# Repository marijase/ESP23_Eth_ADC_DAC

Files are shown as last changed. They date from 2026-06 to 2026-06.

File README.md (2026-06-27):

# Web-Controlled Stereo Signal Generator with Real-Time Signal Analysis

**Author:** Marija Sekulić
**Date:** June 2026

---

## About the project

The system generates digital audio signals of different waveforms (sine, square, triangle) on an ESP32-ETH01 microcontroller, converts them to analog signals using a PCM5102A digital-to-analog converter (DAC), then loops them back into the system through a WM8782S analog-to-digital converter (ADC) where they are analyzed in real time.

The user controls signal parameters — waveform, frequency, and amplitude — through a web application accessible over Ethernet or WiFi. The system displays detected frequency, RMS amplitude, and a real-time oscillogram of the received signal.

---

## Hardware

| Component | Role |
|---|---|
| **ESP32-ETH01** | Microcontroller with Ethernet and WiFi |
| **WM8782S** | 24-bit stereo audio ADC |
| **PCM5102A** | 32-bit stereo audio DAC |
| **USB-TTL adapter** | For firmware upload and serial monitoring |

---

## Features

- Real-time stereo audio signal generation (sine, square, triangle)
- 48 kHz sample rate, 16-bit resolution
- Independent control of left and right channels (frequency, amplitude, mute)
- RMS amplitude calculation
- Real-time signal oscillogram (10 updates per second)
- Responsive web application
- Dual network mode: Ethernet (primary) + WiFi AP (fallback)

---

## Repository structure

```
Projekat/
│
├── HW/                                Hardware
│   └── ESP32_Eth_ADC_DAC/             KiCad project (schematic + PCB)
│       ├── Libs/                      Custom KiCad libraries
│       │   └── ESP32_Eth_ADC_DAC.pretty/  Component footprints
│       ├── ESP32_Eth_ADC_DAC.kicad_pro
│       ├── ESP32_Eth_ADC_DAC.kicad_sch    Electrical schematic
│       ├── ESP32_Eth_ADC_DAC.kicad_pcb    PCB layout
│       └── ...
│
├── SW/                                Software
│   ├── signal_generator/              Main firmware
│   │   ├── signal_generator.ino       Arduino code
│   │   ├── webpage.h                  Web application (HTML/CSS/JS)
│   │   └── README.md
│   │
│   └── blinkanje/                     Test code (blink LED)
│       └── blinkanje.ino
│
└── docs/                              Documentation
    ├── datasheets/                    Component datasheets
    │   ├── ESP32_datasheet_en.pdf
    │   ├── WM8782_datasheet.pdf
    │   ├── WT32-ETH01_datasheet_V1.4_en.pdf
    │   ├── WT32-ETH01_EVO_Datasheet_V2.0_EN.pdf
    │   └── wt32-eth01-v1-4-serial-to-ethernet-module.pdf
    │
    └── dokumentacija.pdf    Main project documentation
```

---

## Technologies used

### Hardware protocols
- **I²S (Inter-IC Sound)** — digital audio protocol between microcontroller and audio chips
- **UART** — serial communication for firmware upload and debugging
- **RMII** — interface between ESP32 and LAN8720A Ethernet PHY chip

### Network protocols
- **Ethernet 10/100 Mbps** — via LAN8720A PHY
- **WiFi 802.11 b/g/n** — in Access Point mode (fallback)
- **HTTP** — web server for serving the page
- **WebSocket** — real-time bidirectional communication

### Software tools
- **Arduino IDE** with ESP32 board package v3.3.8 (Espressif)
- **KiCad** EDA suite for schematic and PCB
- **C/C++** — firmware
- **HTML / CSS / vanilla JavaScript** — web application
- **Chart.js** — library for signal visualization

---

## Pin mapping

### I²S TX (ESP32 master → DAC slave)
| ESP32 pin | DAC pin | Signal |
|---|---|---|
| IO15 (pin 20) | Pin 2 (BCK) | Bit clock |
| IO14 (pin 19) | Pin 4 (LCK) | LR clock |
| IO4 (pin 16) | Pin 3 (DIN) | Audio data |

### I²S RX (ADC master → ESP32 slave)
| ADC pin | ESP32 pin | Signal |
|---|---|---|
| Pin 1 (B) | IO36 (pin 21) | Bit clock |
| Pin 2 (LR) | IO39 (pin 22) | LR clock |
| Pin 3 (D) | IO35 (pin 17) | Audio data |

### Audio loopback
| From | To |
|---|---|
| DAC pin 7 (LROUT) | ADC pin 9 (Lin) |
| DAC pin 9 (ROUT) | ADC pin 7 (Rin) |

---

## Getting started

### 1. Hardware assembly

Connect the components according to the electrical schematic in `HW/ESP32_Eth_ADC_DAC/`. Detailed instructions and connection tables are available in the main documentation.

### 2. ADC module configuration

Set the DIP switch on the WM8782S module:

| Switch | Position | Function |
|---|---|---|
| 1 (M/S) | + | Master mode |
| 2 (Format) | 0 | I²S format |
| 3 (Sample rate) | − | 48 kHz |
| 4 (Bits) | − | 16-bit |

### 3. Development environment setup

1. Install **Arduino IDE** (from arduino.cc)
2. Add ESP32 board package:
   - File → Preferences → Additional Boards Manager URLs:
     `https://espressif.github.io/arduino-esp32/package_esp32_index.json`
   - Tools → Board → Boards Manager → install **esp32** (v3.3.8)
3. Install **WebSockets** library (Markus Sattler) via Library Manager

### 4. Arduino IDE configuration

- Tools → Board → esp32 → **WT32-ETH01 Ethernet Module**
- Upload Speed: **115200**
- Flash Frequency: **80MHz**
- Flash Mode: **QIO**
- Partition Scheme: **Default 4MB with spiffs**

### 5. Firmware upload

1. Unplug USB-TTL from the laptop
2. Connect ESP32 IO0 (pin 24) to GND (boot mode)
3. Plug in USB-TTL
4. Open `SW/signal_generator/signal_generator.ino`
5. Click **Upload**
6. During "Connecting...." unplug and plug EN pin back
7. After upload: unplug USB, remove IO0 from GND, plug USB back

### 6. Accessing the web application

**Via Ethernet cable (recommended):**
1. Connect a UTP cable from the ESP32 RJ45 to a free LAN port on the router
2. Open Serial Monitor (115200 baud) and read the IP address
3. Open that IP address in a browser

**Via WiFi AP (fallback):**
1. Connect to the WiFi network **ESP32-Signal-Generator** (password: `12345678`)
2. Open `http://192.168.4.1` in a browser

---

## Technical details

### I²S configuration

The ESP32 has two independent I²S controllers:
- **I²S0** — master TX channel to the DAC (generates BCK and LRCK)
- **I²S1** — slave RX channel from the ADC (receives BCK and LRCK from the ADC)

Since the WM8782S ADC is configured as master (using its onboard 24.576 MHz and 22.5792 MHz crystals), and the PCM5102A DAC is always a slave, using both ESP32 I²S controllers is required.

### Signal generation

Audio samples are computed in software, sample by sample (48000 times per second per channel), in the main loop. For each sample the current signal phase is calculated and converted to a 16-bit signed integer, which is written to the I²S DMA buffer.

### Signal analysis

- **RMS amplitude:** square root of the mean of squared samples in the buffer
- **Frequency:** zero-crossing detection (number of negative-to-positive transitions divided by buffer duration)

### WebSocket communication

Bidirectional real-time communication on port 81:
- **ESP32 → client:** 10 updates per second with JSON payload (detected frequency, RMS, array of 128 samples for oscillogram)
- **Client → ESP32:** commands on every slider move or button click

---

## Demonstration

The system supports the following features for demonstration:

- **Stereo signal generation** — different frequencies on L and R channels simultaneously
- **Real-time waveform switching** — sine, square, triangle
- **Independent channel muting**
- **Audio output via 3.5mm jack** — direct headphone connection
- **Real-time visualization** — oscillogram of the received signal
- **Dual-mode networking** — automatic fallback from Ethernet to WiFi AP

---

## License
...

---

# Youtube video:
[text](https://youtu.be/xQKN2IF4LF8?si=VLTadd05omXWZXxb)

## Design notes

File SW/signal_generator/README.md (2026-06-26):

# Signal Generator + Monitor

ESP32-ETH01 + WM8782S ADC + PCM5102A DAC sa web kontrolama preko Ethernet/WiFi.

---

## Šta projekat radi

1. ESP32 generiše stereo audio signal (sinus / kvadrat / trougao) i šalje ga DAC-u preko I²S
2. DAC ga pretvara u analogni signal koji ide u zvučnik / loopback ka ADC-u
3. ADC snima taj signal i šalje ga nazad ESP32-u
4. ESP32 analizira primljeni signal (frekvencija, RMS amplituda)
5. Web stranica prikazuje rezultate u realnom vremenu i omogućava kontrolu

---

## Sadržaj foldera

```
signal_generator/
├── signal_generator.ino     ← glavni Arduino fajl
├── webpage.h                ← HTML/CSS/JS web stranica
└── README.md                ← ovaj fajl
```

**Važno:** folder MORA da se zove `signal_generator` jer je glavni fajl `signal_generator.ino`. Arduino IDE zahteva da se folder zove isto kao i glavni .ino fajl.

---

## Priprema Arduino IDE-a

### 1. Instalacija ESP32 board package-a

Verovatno već imaš (verzija 3.3.8). Ako ne:
- File → Preferences → Additional Boards Manager URLs:
  `https://espressif.github.io/arduino-esp32/package_esp32_index.json`
- Tools → Board → Boards Manager → traži "esp32" → instaliraj

### 2. Instalacija dodatnih biblioteka

Sketch → Include Library → Manage Libraries → traži i instaliraj:

| Biblioteka | Autor |
|---|---|
| **WebSockets** | Markus Sattler |

Ostale (`WebServer`, `WiFi`, `ETH`, `driver/i2s.h`) dolaze sa ESP32 board package-om.

### 3. Selekcija board-a

- Tools → Board → esp32 → **"WT32-ETH01"**

Ako "WT32-ETH01" nije izlistan, izaberi **"ESP32 Dev Module"** — sve radi isto.

### 4. Upload settings

- Upload Speed: **115200**
- CPU Frequency: **240MHz**
- Flash Frequency: **40MHz**
- Flash Size: **4MB (32Mb)**
- Partition Scheme: **Default 4MB**

---

## Upload koda na ESP32

ESP32-ETH01 nema USB port — koristi USB-UART dongle, baš kao za blink test.

### Povezivanje za upload

```
USB-UART dongle    ESP32-ETH01
─────────────────  ─────────────
    TX        →    pin 7  (RXD)
    RX        →    pin 8  (TXD)
    GND       →    pin 2  (GND)
    5V        →    pin 12 (5V)
```

### Procedura uploada

1. **Pripremi za boot mod:** spoji IO0 (pin 24) na GND
2. **Resetuj ESP32:** kratko prekini napajanje (skini i vrati USB dongle)
3. U Arduino IDE klikni **Upload**
4. Sačekaj da se završi (~30 sekundi)
5. **Otkači IO0 sa GND-a**
6. Ponovo resetuj ESP32 (prekini napajanje)

Ako ne ide, proveri da li su TX/RX žice zamenjene — to je najčešća greška.

---

## Pristup web stranici

### Preko Ethernet kabla (default)

1. Spoji RJ45 kabl od ESP32-ETH01 na router (ili direktno na laptop)
2. Otvori **Serial Monitor** u Arduino IDE (115200 baud)
3. Resetuj ESP32 — videćeš ispis sa IP adresom, npr:
   ```
   [ETH] IP adresa: 192.168.1.123
   Otvori u pretrazivacu: http://192.168.1.123
   ```
4. Otvori tu IP adresu u pretraživaču na laptopu/telefonu

### Preko WiFi-ja (fallback)

Ako Ethernet kabl nije povezan u roku od 3 sekunde od starta, ESP32 automatski pokreće WiFi Access Point:

1. Na telefonu/laptopu uđi u WiFi podešavanja
2. Poveži se na mrežu **"ESP32-Signal-Generator"** sa lozinkom **"12345678"**
3. Otvori u pretraživaču: **http://192.168.4.1**

---

## Korišćenje web stranice

Stranica ima dva dela:

### Levi kanal (L) i Desni kanal (R)

Za svaki kanal možeš nezavisno podesiti:
- **Oblik talasa**: Sinus / Kvadrat / Trougao
- **Frekvencija**: klizač 100–5000 Hz
- **Amplituda**: klizač 0–100%
- **Mute**: dugme za isključivanje kanala

### Analiza primljenog signala (loopback)

Ispod kontrola, za svaki kanal prikazuje se:
- **Detektovana frekvencija** — koja bi trebalo da bude jednaka onoj koju šalješ (ovo dokazuje da loopback radi)
- **RMS amplituda** — efektivna jačina signala

### Oscilogram

Donji deo stranice prikazuje grafiku primljenog signala (oba kanala) u realnom vremenu, 10 puta u sekundi.

---

## Šta očekivati pri prvom pokretanju

Posle uspešnog uploada i resetovanja, na **Serial Monitor**-u trebalo bi da vidiš:

```
================================================
  Signal Generator + Monitor
  ESP32-ETH01 + WM8782S ADC + PCM5102A DAC
================================================

[INIT] Pokusavam Ethernet...
[ETH] Start
[ETH] Kabl povezan
[ETH] IP adresa: 192.168.1.123
[INIT] Ethernet aktivan
[I2S] Inicijalizacija TX (DAC) - master mod...
[I2S TX] OK
[I2S] Inicijalizacija RX (ADC) - slave mod...
[I2S RX] OK
[HTTP] Server pokrenut na portu 80
[WS] Server pokrenut na portu 81

================================================
  Otvori u pretrazivacu: http://192.168.1.123
================================================
```

---

## Troubleshooting

### Problem: Upload ne uspeva

- IO0 mora biti na GND tokom uploada
- TX/RX žice mogu biti zamenjene
- Resetuj ESP32 pre kliktanja Upload

### Problem: Stranica se učitava ali analiza pokazuje 0 Hz

- Loopback (DAC LROUT → ADC Lin) nije fizički povezan
- Proveri jumpere JP5 i JP6 — moraju biti zatvoreni
- DAC XSMT pin mora biti na 3.3V (un-mute)

### Problem: Detektovana frekvencija je dvostruko veća/manja

- Sample rate ADC i DAC nisu sinhronizovani
- Proveri DIP switch na ADC modulu — svi OFF (default)

### Problem: Šum / pucketanje u signalu

- Loš jumper kabl ili labava veza
- Proveri da li su sve GND linije spojene
- Možda treba decoupling kondenzator (100nF + 10μF) između VIN i GND na svakom modulu

### Problem: Nema pristupa web stranici

- Proveri IP adresu na Serial Monitor-u
- Proveri da li si u istoj mreži kao ESP32
- Probaj ping na IP adresu sa laptopa

---

## Tehnički detalji

| Parametar | Vrednost |
|---|---|
| Sample rate | 48 kHz |
| Bit dubina | 16-bit signed |
| Kanali | Stereo (L + R nezavisno) |
| I²S TX kontroler | I2S_NUM_0, ESP32 master |
| I²S RX kontroler | I2S_NUM_1, ESP32 slave (ADC je master) |
| Mreža | Ethernet + WiFi AP fallback |
| HTTP port | 80 |
| WebSocket port | 81 |
| Real-time prikaz | 10× u sekundi |

---

## Pinovi (rekapitulacija prema KiCad šemi)

| Funkcija | ESP32 GPIO | Komponenta |
|---|---|---|
| I²S TX BCLK | IO15 | DAC pin 2 (BCK) |
| I²S TX LRCK | IO14 | DAC pin 4 (LCK) |
| I²S TX DATA | IO4 | DAC pin 3 (DIN) |
| I²S RX BCLK | IO36 | ADC pin 1 (B) |
| I²S RX LRCK | IO39 | ADC pin 2 (LR) |
| I²S RX DATA | IO35 | ADC pin 3 (D) |

---

Marija Sekulić · RTRK · jun 2026

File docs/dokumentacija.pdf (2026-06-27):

# Dokumentacija projekta

### Web-kontrolisani stereo signal generator sa analizom signala u realnom vremenu

ESP32-ETH01 + WM8782S ADC + PCM5102A DAC

Student: Marija Sekulić RA194/2022
Predmet: Logičko projektovanje računarskih sistema 2

Fakultet tehničkih nauka, Univerzitet u Novom Sadu jun 2026.

## 1. Uvod

Cilj projekta je realizacija sistema koji generiše digitalne audio signale različitih oblika (sinus, kvadrat, trougao) preko ESP32-ETH01 mikrokontrolera, konvertuje ih u analogne signale pomoću PCM5102A DAC-a, i kroz loopback povratnu spregu vraća u sistem preko WM8782S ADC-a gde se analiziraju u realnom vremenu.

Korisnik upravlja parametrima signala kroz web aplikaciju dostupnu preko Ethernet ili WiFi mreže. Sistem prikazuje detektovanu frekvenciju, RMS amplitudu i oscilogram primljenog signala u realnom vremenu.

### Komponente sistema

- ESP32-ETH01
- WM8782S ADC
- PCM5102A DAC
- USB-TTL adapter

### Faze projekta

- Istraživanje komponenti i analiza pinova
- Projektovanje električne šeme i PCB-a u KiCad-u
- Fizička realizacija na breadboard-u i lemljenje PCB-a
- Razvoj firmvera (Arduino IDE, C/C++) i web aplikacije

## 2. Analiza komponenti

Prvi korak je bila analiza svake komponente — proučavanje datasheet-ova, određivanje uloga svakog pina i planiranje načina povezivanja.

### 2.1 ESP32-ETH01

Modul koji kombinuje ESP32 čip (procesor sa ugrađenim WiFi i Bluetooth) sa LAN8720A Ethernet PHY čipom i RJ45 konektorom. Programiranje preko spoljnog USB-TTL adaptera.

Karakteristike

Parametar | Vrednost
Radni napon | +5 V (preko regulatora) ili +3.3 V
Logički nivo GPIO | 3.3 V
Tipična potrošnja | ~80–160 mA
Ethernet brzina | 10/100 Mbps (LAN8720A PHY)
WiFi | 802.11 b/g/n
Procesor | Xtensa LX6 dvojezgarni, do 240 MHz
Memorija | 520 KB SRAM, 4 MB Flash

Korišćeni pinovi

Pin | Naziv | Tip | Uloga
1 | EN | Ulazni | Enable, na +3.3V
2 | GND | Napajanje | Masa
3 | 3V3 | Napajanje (izlaz) | Izlaz 3.3V regulatora
7 | RXD | Ulazni UART | UART prijem
8 | TXD | Izlazni UART | UART predaja
12 | 5V | Napajanje | Glavno +5V napajanje
16 | IO4 | I/O | I²S DATA OUT (ka DAC)
17 | IO35 | Samo ulazni | I²S DATA IN (od ADC)
19 | IO14 | I/O | I²S TX LRCK (ka DAC)
20 | IO15 | I/O | I²S TX BCLK (ka DAC)
21 | IO36 | Samo ulazni | I²S RX BCLK (od ADC)
22 | IO39 | Samo ulazni | I²S RX LRCK (od ADC)
24 | IO0 | I/O + boot | Boot mod (na GND pri uploadu)

### 2.2 PCM5102A — Stereo audio DAC

32-bitni stereo digitalno-analogni konvertor sa I²S ulazom (Texas Instruments). Modul ima ugrađen low-jitter PLL koji generiše interni system clock iz BCK signala (zbog čega se SCK pin vezuje na masu), i 3.5 mm audio jack za direktno priključivanje slušalica.

Karakteristike

Parametar | Vrednost
Radni napon | +3.3 V do +5 V
Rezolucija | 32 bita (radi i sa 16/24-bitnim)
Sample rate | 8 kHz – 384 kHz
SNR | 112 dB (A-weighted)
Maksimalni izlaz | 2.1 Vrms
Master/Slave | Uvek SLAVE

Pinovi

Pin | Naziv | Tip | Uloga
1 | SCK | Ulazni (takt) | System clock — na GND (interna PLL)
2 | BCK | Ulazni (takt) | Bit clock – od ESP32 IO15
3 | DIN | Ulazni | Audio podaci – od ESP32 IO4
4 | LCK | Ulazni (takt) | LR clock – od ESP32 IO14
5 | GND | Napajanje | Digitalna masa
6 | VIN | Napajanje | Napajanje +5V
7 | LROUT | Analogni izlaz | Levi audio izlaz
8 | AGND | Napajanje | Analogna masa
9 | ROUT | Analogni izlaz | Desni audio izlaz
10 | AGND | Napajanje | Analogna masa
11 | A3V3 | Napajanje | Analogno napajanje +3.3V
12 | FMT | Kontrolni | Audio format (GND = I²S)
13 | XSMT | Kontrolni | Soft mute (3.3V = un-mute)
14 | DEMP | Kontrolni | De-emphasis (GND = off)
15 | FLT | Kontrolni | Filter (GND = normal)

### 2.3 WM8782S — Stereo audio ADC

24-bitni stereo analogno-digitalni konvertor sa I²S izlazom. Modul ima dva kristalna oscilatora (24.576 MHz i 22.5792 MHz) za različite familije sample rate-a, AMS1117 LDO regulator napona 3.3V, DIP switch za izbor moda, i elektrolitske kondenzatore na analognim ulazima.

Karakteristike

Parametar | Vrednost
Radni napon | +5 V (preko AMS1117 regulatora)
Rezolucija | 24 bita
Sample rate | 32 / 44.1 / 48 / 88.2 / 96 / 192 kHz
SNR | 100 dB (A-weighted)
Maksimalni ulaz | 2 Vrms
Master/Slave | MASTER (u ovom modulu)

Pinovi

Pin | Naziv | Tip | Uloga
1 | B (BCK) | Izlazni | Bit clock — ka ESP32 IO36
2 | LR (LRCK) | Izlazni | LR clock — ka ESP32 IO39
3 | D (DATA) | Izlazni | Audio podaci — ka ESP32 IO35
4 | CLK
| (MCLK) | Izlazni | Master clock — nepovezan
5 | GND | Napajanje | Masa
6 | +5V | Napajanje | Napajanje +5V
7 | Rin | Analogni ulaz | Desni audio ulaz
9 | Lin | Analogni ulaz | Levi audio ulaz

DIP switch
Modul ima 4 prekidača za izbor moda. U projektu se koristi default konfiguracija — svi prekidači u poziciji 0 (OFF).

## 3. Povezivanje komponenti

U I²S komunikaciji jedan uređaj je master (generiše takte BCK i LRCK), a drugi je slave (samo prima takte). U ovom sistemu:

- WM8782S ADC je MASTER — koristi sopstvene kristale za BCK i LRCK
- PCM5102A DAC je SLAVE — prima takte i podatke spolja
- ESP32 je istovremeno MASTER i SLAVE — koristi dva I²S kontrolera. I²S0 master (TX → DAC), I²S1 slave (RX ← ADC)

Napajanje

Od | Pin | Do | Pin
USB-TTL | 5V | šina protoborda | +5V
USB-TTL | GND | šina protoborda | GND
+5V šina | — | ESP32-ETH01 | Pin 12 (5V)
+5V šina | — | WM8782S ADC | +5V
+5V šina | — | PCM5102A DAC | Pin 6 (VIN)
ESP32-ETH01 | Pin 3 (3V3) | +3.3V šina | —
+3.3V šina | — | ESP32-ETH01 | Pin 1 (EN)
+3.3V šina | — | PCM5102A DAC | Pin 11 (A3V3)
+3.3V šina | — | PCM5102A DAC | Pin 13 (XSMT)

I²S TX (ESP32 → DAC)

Od | Pin | Do | Pin
ESP32 | IO15 (pin 20) | DAC | Pin 2 (BCK)
ESP32 | IO14 (pin 19) | DAC | Pin 4 (LCK)
ESP32 | IO4 (pin 16) | DAC | Pin 3 (DIN)
GND | — | DAC | Pin 1 (SCK)

I²S RX (ADC → ESP32)

Od | Pin | Do | Pin
ADC | Pin 1 (B) | ESP32 | IO36 (pin 21)
ADC | Pin 2 (LR) | ESP32 | IO39 (pin 22)
ADC | Pin 3 (D) | ESP32 | IO35 (pin 17)

DAC kontrolni pinovi

DAC pin | Veza | Značenje
Pin 12 (FMT) | GND | I²S format
Pin 14 (DEMP) | GND | De-emphasis off
Pin 15 (FLT) | GND | Normal latency
Pin 13 (XSMT) | +3.3V | Un-mute (DAC aktivan)
Pin 8, 10 (AGND) | GND | Analogna masa

Audio loopback (DAC → ADC)
Glavna veza projekta — analogni izlaz DAC-a direktno se vraća u ADC ulaz, što omogućava verifikaciju da li je signal koji je sistem generisao uspešno reprodukovan i ponovo digitalizovan.
Od | Pin | Do | Pin
DAC | Pin 7 (LROUT) | ADC | Pin 9 (Lin)
DAC | Pin 9 (ROUT) | ADC | Pin 7 (Rin)

UART (programiranje)

Od | Pin | Do | Pin
USB-TTL | TX | ESP32 | Pin 7 (RXD)
USB-TTL | RX | ESP32 | Pin 8 (TXD)

## 4. Električna šema i PCB

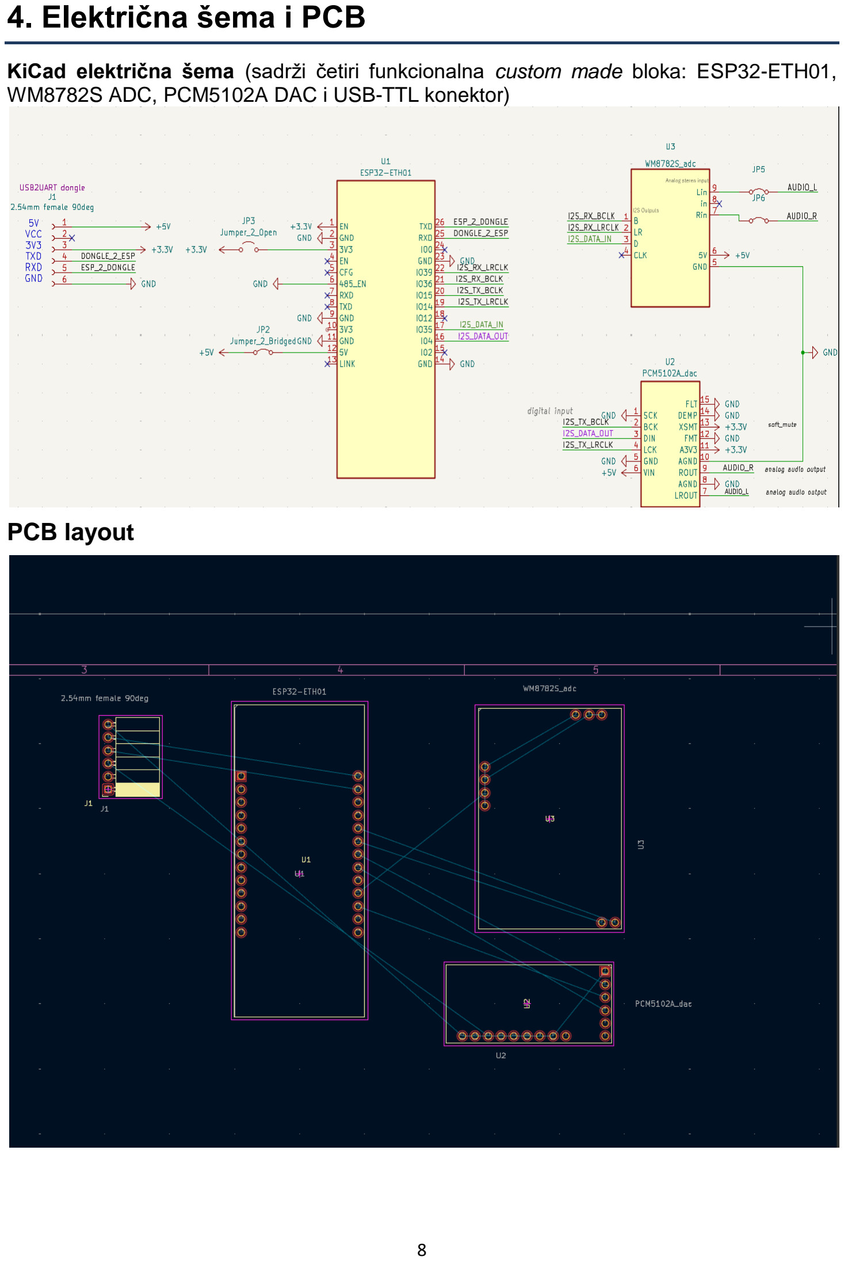
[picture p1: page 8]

KiCad električna šema (sadrži četiri funkcionalna custom made bloka: ESP32-ETH01, WM8782S ADC, PCM5102A DAC i USB-TTL konektor)

### PCB layout

## 5. Fizička realizacija

Pre lemljenja PCB-a, sistem je sastavljen na breadboard-u (protobordu) i testiran. Ovaj korak omogućava verifikaciju ispravnosti šeme i firmvera pre konačnog lemljenja. Komponente su
povezane | jumper | kablovima | prema | tabeli | veza | iz | poglavlja | 3.

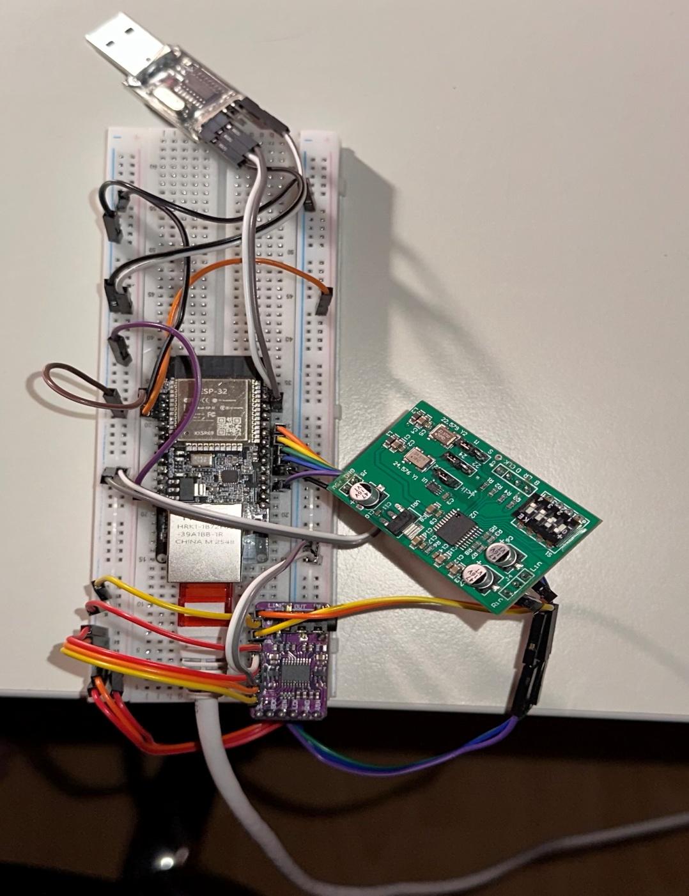
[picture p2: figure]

### 5.1 Provera ispravnosti pre uključenja

Pre prvog uključenja sistema izvršena je sistematska provera povezivanja digitalnim multimetrom (VC830L):

- Provera otpornosti između +5V i GND linija (ne sme pokazati 0Ω — kratak spoj)
- Provera otpornosti između +3.3V i GND linija
- Provera kontinuiteta svake mase prema zajedničkoj GND šini
- Provera da su +5V i +3.3V odvojene linije (ne smeju biti spojene)

### 5.2 Provera napona nakon uključenja

Tačka | Očekivano | Značenje
+5V šina | ~5 V | Napajanje stiže
ESP32 pin 3 (3V3) | ~3.3 V | ESP32 regulator radi
DAC pin 11 (A3V3) | ~3.3 V | DAC analogno napajanje
ADC +5V | ~5 V | ADC napajanje
DAC pin 1 (SCK) | 0 V | System clock na GND
DAC pin 13 (XSMT) | ~3.3 V | DAC nije muted

## 6. Softverska realizacija

Projekat je razvijen u Arduino IDE okruženju (C/C++ jezik, ESP32 board package 3.3.8). Web aplikacija u HTML/CSS/JavaScript-u, koristeći Chart.js biblioteku za vizualizaciju signala.

Struktura projekta:
- signal_generator.ino - Glavni firmware — I²S, generisanje signala, analiza, mreža
- webpage.h - HTML/CSS/JavaScript web aplikacije (u flash memoriji)

### 6.1 I²S protokol

I²S (Inter-IC Sound) je serijski protokol za prenos digitalnog audio signala između integrisanih kola. Razvijen od strane Philips-a 1986. godine, danas je industrijski standard za digitalni audio.

Signali u I²S protokolu
- BCLK (Bit Clock) — sat koji odbrojava svaki bit podataka. Za 48 kHz / 16-bit / stereo: 48000 × 16 × 2 = 1.536 MHz
- LRCK / WS (Word Select) — sat koji bira da li se prenosi levi ili desni kanal. Frekvencija = sample rate (48 kHz)
- SD / DATA — serijska linija sa audio podacima (16-bitni signed integer)

ESP32 I²S konfiguracija
ESP32 ima dva nezavisna I²S kontrolera. U projektu je I²S0 konfigurisan kao master TX (šalje podatke DAC-u), a I²S1 kao slave RX (prima podatke od ADC-a). Sample rate 48 kHz, bitska dubina 16, format stereo.

### 6.2 Mrežna komunikacija

Sistem podržava dva načina pristupa web aplikaciji — Ethernet (primarni) i WiFi Access Point (rezervni). Pri startu, firmware pokušava Ethernet konekciju; ako u 3 sekunde nije detektovan kabl, prebacuje se na WiFi.
Ethernet - ESP32 – ETH01 koristi LAN8720A PHY čip sa RMII interfejsom. Konekcija sa lokalnom mrežom preko UTP kabla i kućnog rutera, koji dodeljuje IP adresu kroz DHCP.

WiFi Access Point – Ako Ethernet nije dostupan, ESP32 pokreće WiFi mrežu sa SSID "ESP32-Signal-Generator" i lozinkom "12345678". Aplikacija je dostupna na http://192.168.4.1.

### 6.3 HTTP server

Firmware sadrži HTTP server (biblioteka WebServer.h) koji slušа na portu 80. Dve glavne rute:

- GET / — vraća HTML stranicu (iz webpage.h)
- GET /status — vraća JSON sa trenutnim stanjem sistema

### 6.4 WebSocket protokol

WebSocket je protokol koji omogućava dvosmernu komunikaciju u realnom vremenu između web pretraživača i ESP32-a. Za razliku od HTTP-a (request-response model), WebSocket uspostavlja trajnu vezu preko koje obe strane mogu slati poruke u bilo kom trenutku.

U projektu se koristi za dva smera:
- ESP32 → pretraživač: 10 puta u sekundi šalje JSON sa detektovanom frekvencijom, RMS amplitudom i 128 uzoraka signala za oscilogram
- Pretraživač → ESP32: pri pomeranju klizača šalje komandu ("freq_left=2000", "wave_right=1") koja se odmah primenjuje
WebSocket server radi na portu 81 (Markus Sattler WebSockets biblioteka, v2.7.2).

### 6.5 Generisanje signala

Sinusni, kvadratni i trougaoni signali se računaju u softveru, uzorak po uzorak (48000 puta u sekundi po kanalu) u glavnoj petlji. Za svaki uzorak se izračuna trenutna faza, konvertuje u 16-bitni signed integer i upiše u I²S DMA buffer.

Sinusni: y = sin(2π × f × t). Kvadratni: y = ±1 zavisno od znaka sin(2π × f × t). Trougaoni: linearno rastuća pa opadajuća rampa.

Signal koji ESP32 prima od ADC-a se analizira u realnom vremenu:

- RMS amplituda — kvadratni koren prosečnog kvadrata uzoraka u baferu
- Detektovana frekvencija — metodom detekcije prelazaka kroz nulu (zero-crossing) — broji se prelaska iz negativne u pozitivnu vrednost i deli sa trajanjem bafera

### 6.6 Web aplikacija

Single-page aplikacija (sav HTML/CSS/JS u webpage.h fajlu). Tamni dizajn sa dva panela (levi kanal — plavi, desni — narandžasti), klizače za frekvenciju i amplitudu, dugmad za izbor oblika talasa, prikaz detektovanih vrednosti i oscilogram u realnom vremenu (Chart.js).

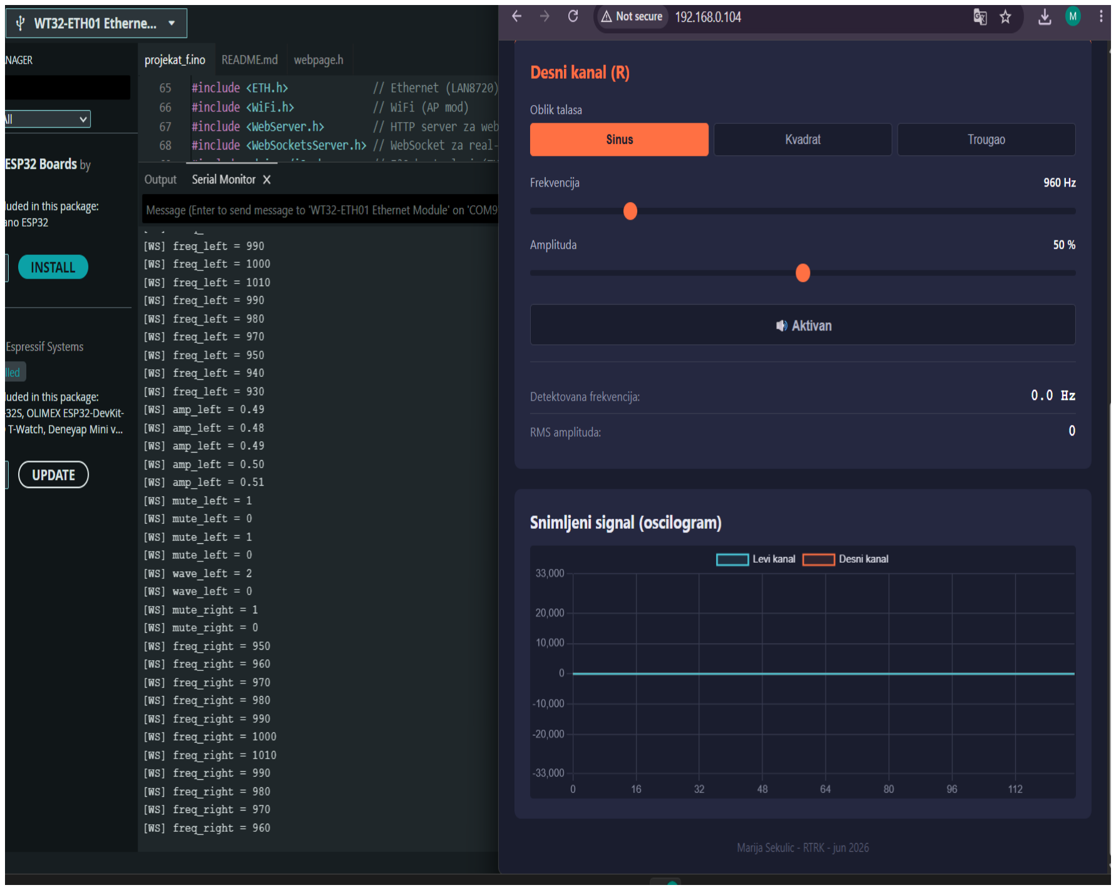
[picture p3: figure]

Pri otvaranju, JavaScript uspostavlja WebSocket konekciju i počinje da prima podatke od ESP32-a. Svako pomeranje klizača automatski šalje komandu, što omogućava trenutnu reakciju bez učitavanja stranice.

## 7. Zaključak

Sistem demonstrira kombinaciju više različitih tehnologija — embedded development, digitalna audio obrada (I²S protokol, ADC/DAC konvertori), poznavanje osnova elektronike (realizacija na breadboard-u), mrežne komunikacije (Ethernet, WiFi, HTTP) i web razvoj (responzivni dizajn, real-time vizualizacija).

Iz projekta je izostavljen deo lemljenja, pa je realizovan samo na protobordu, zbog čega su prisutne poteškoće prilikom prikaza ADC rezultata u aplikaciji, međutim ipak u jednom navratu je uspešno zabeležen i taj trenutak:

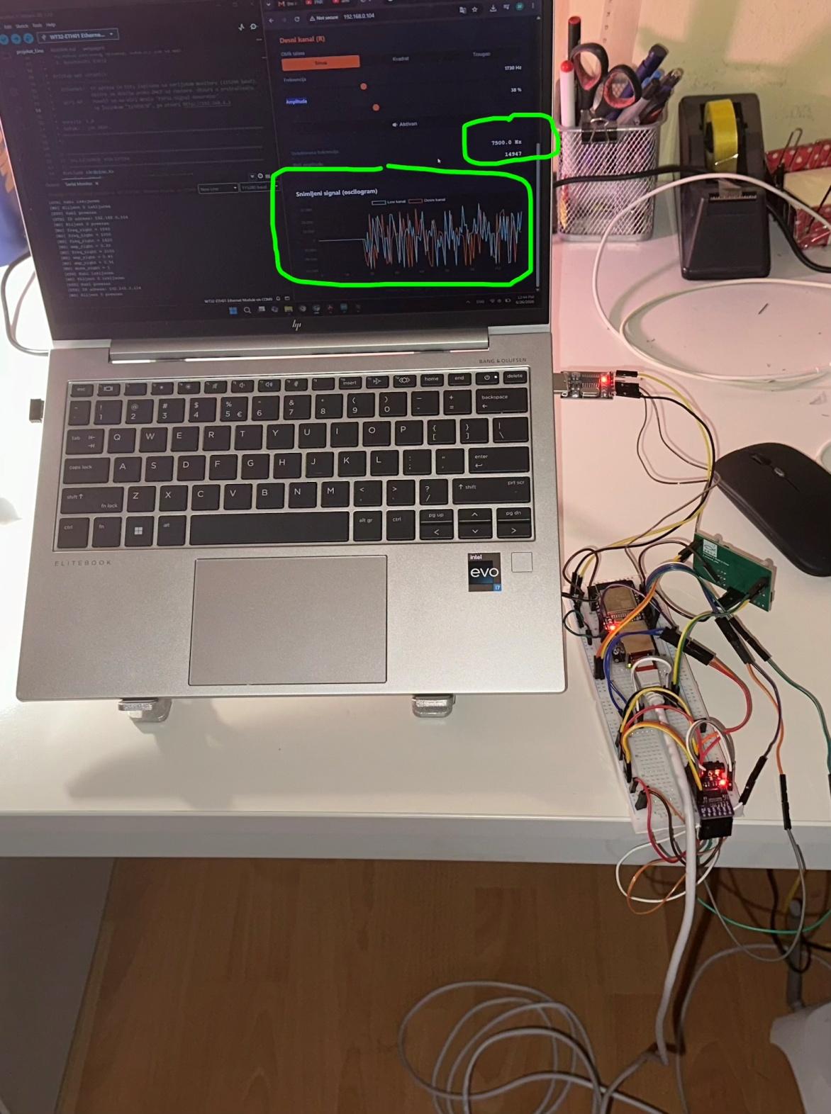
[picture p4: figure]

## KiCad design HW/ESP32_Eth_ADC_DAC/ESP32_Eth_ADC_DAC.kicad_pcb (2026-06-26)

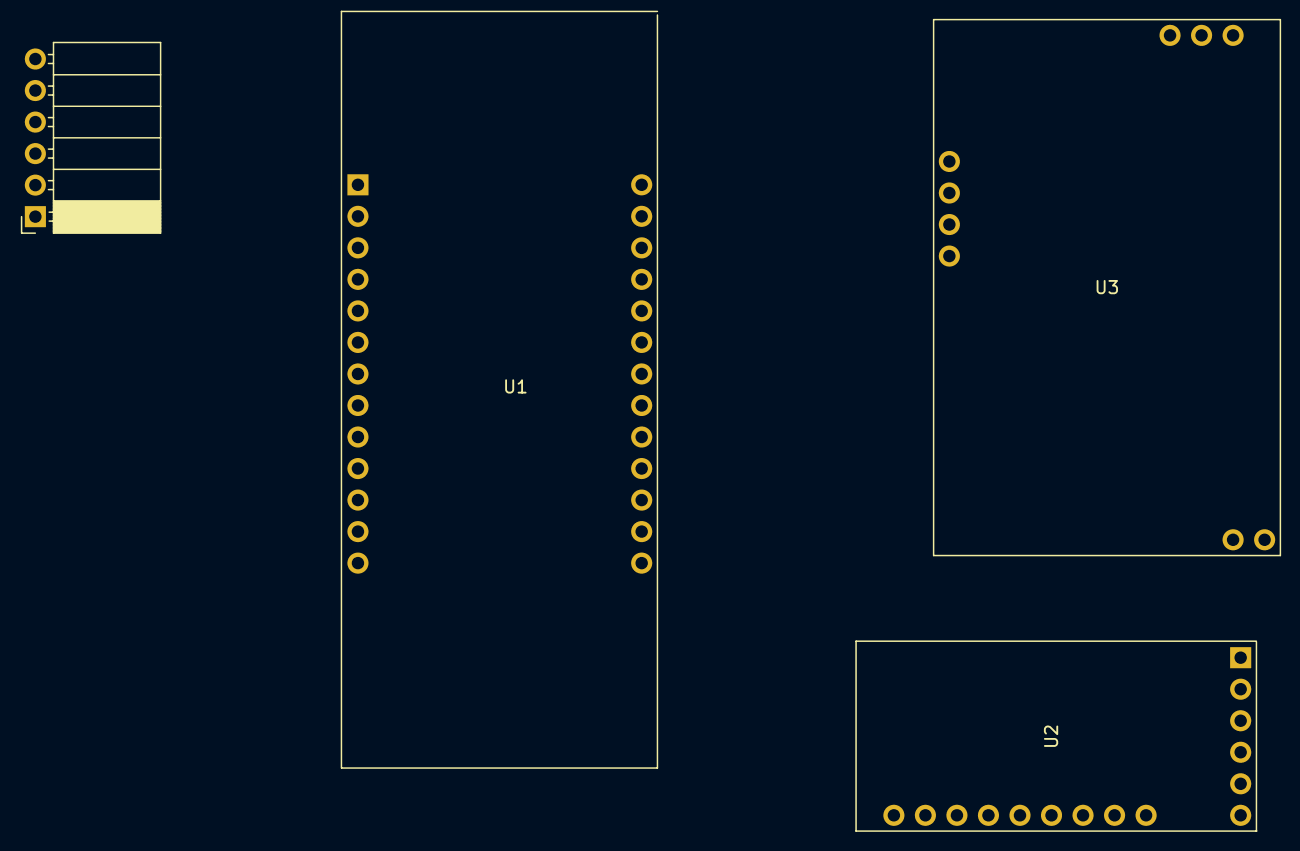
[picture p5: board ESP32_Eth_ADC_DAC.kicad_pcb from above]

Board: 2 copper layers, 4 parts (0 on the bottom side), 10 nets, no tracks yet.

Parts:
J1: 2.54mm female 90deg; PinSocket_1x06_P2.54mm_Horizontal
U1: ESP32-ETH01
U2: PCM5102A_dac
U3: WM8782S_adc

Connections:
+3.3V: J1.3, U2.11 (A3V3), U2.13 (XSMT)
/DONGLE_2_ESP: J1.4, U1.25 (RXD)
/ESP_2_DONGLE: J1.5, U1.26 (TXD)
/I2S_DATA_IN: U1.17 (IO35), U3.3 (D)
/I2S_DATA_OUT: U1.16 (IO4), U2.3 (DIN)
/I2S_RX_BCLK: U1.21 (IO36), U3.1 (B)
/I2S_RX_LRCLK: U1.22 (IO39), U3.2 (LR)
/I2S_TX_BCLK: U1.20 (IO15), U2.2 (BCK)
/I2S_TX_LRCLK: U1.19 (IO14), U2.4 (LCK)
GND: J1.6, U1.6 (485_EN), U2.1 (SCK), U2.8 (AGND), U2.10 (AGND), U2.12 (FMT), U2.14 (DEMP), U2.15 (FLT)

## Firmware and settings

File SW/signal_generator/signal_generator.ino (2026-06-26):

#include <Arduino.h>
#include <ETH.h>              // Ethernet (LAN8720)
#include <WiFi.h>             // WiFi (AP mod)
#include <WebServer.h>        // HTTP server for web page
#include <WebSocketsServer.h> // WebSocket for real-time data on graphic
#include <driver/i2s.h>       // I²S controllers (TX for DAC, RX for ADC)
#include <math.h>             // sin(), fabs()

#include "webpage.h"          // HTML/CSS/JS web page (array charactrers)


// ----- I²S TX (ESP32 → DAC) -----
#define I2S_TX_PORT       I2S_NUM_0
#define I2S_TX_BCLK_PIN   15      // → DAC pin 2 (BCK)
#define I2S_TX_LRCK_PIN   14      // → DAC pin 4 (LCK)
#define I2S_TX_DOUT_PIN    4      // → DAC pin 3 (DIN)

// ----- I²S RX (ADC → ESP32) -----
#define I2S_RX_PORT       I2S_NUM_1
#define I2S_RX_BCLK_PIN   36      // ← ADC pin 1 (B)
#define I2S_RX_LRCK_PIN   39      // ← ADC pin 2 (LR)
#define I2S_RX_DIN_PIN    35      // ← ADC pin 3 (D)

// ----- Audio parameters -----
#define SAMPLE_RATE       48000   // 48 kHz 
#define BITS_PER_SAMPLE   16      // 16-bit signed integer per sample per channel
#define BUFFER_SAMPLES    256     // size audio buffer (per channel)
#define DMA_BUF_COUNT     8       // DMA buffer number
#define DMA_BUF_LEN       64      // size of each DMA buff

// ----- Network -----
#define WIFI_AP_SSID      "ESP32-Signal-Generator"
#define WIFI_AP_PASSWORD  "12345678"
#define ETH_TIMEOUT_MS    3000    // 3 seconds for detection Ethernet connection
#define HTTP_PORT         80
#define WEBSOCKET_PORT    81

enum WaveformType {
  WAVEFORM_SINE     = 0,
  WAVEFORM_SQUARE   = 1,
  WAVEFORM_TRIANGLE = 2
};


bool eth_connected = false;
bool wifi_ap_active = false;
String active_network = "Initializing...";
String ip_address = "0.0.0.0";

WebServer http_server(HTTP_PORT);
WebSocketsServer ws_server(WEBSOCKET_PORT);

volatile WaveformType wave_left  = WAVEFORM_SINE;
volatile WaveformType wave_right = WAVEFORM_SINE;
volatile float freq_left  = 1000.0;  // Hz
volatile float freq_right = 1000.0;  // Hz
volatile float amp_left   = 0.5;     // 0.0 - 1.0
volatile float amp_right  = 0.5;     // 0.0 - 1.0
volatile bool  mute_left  = false;
volatile bool  mute_right = false;

double phase_left  = 0.0;
double phase_right = 0.0;

volatile float detected_freq_left  = 0.0;
volatile float detected_freq_right = 0.0;
volatile float rms_left            = 0.0;
volatile float rms_right           = 0.0;

// audio buffers  (interleaved L/R)
int16_t tx_buffer[BUFFER_SAMPLES * 2];  // 2 jer je stereo
int16_t rx_buffer[BUFFER_SAMPLES * 2];

#define GRAPH_SAMPLES 128
int16_t graph_buffer_left[GRAPH_SAMPLES];
int16_t graph_buffer_right[GRAPH_SAMPLES];

// time tracking 
unsigned long last_websocket_send = 0;
const unsigned long WEBSOCKET_INTERVAL_MS = 100;  // 10× per second

//  ETHERNET — handler event 
void onEthEvent(WiFiEvent_t event) {
  switch (event) {
    case ARDUINO_EVENT_ETH_START:
      Serial.println("[ETH] Start");
      ETH.setHostname("esp32-signal-gen");
      break;
    case ARDUINO_EVENT_ETH_CONNECTED:
      Serial.println("[ETH] Kabl povezan");
      break;
    case ARDUINO_EVENT_ETH_GOT_IP:
      Serial.print("[ETH] IP adresa: ");
      Serial.println(ETH.localIP());
      eth_connected = true;
      ip_address = ETH.localIP().toString();
      active_network = "Ethernet";
      break;
    case ARDUINO_EVENT_ETH_DISCONNECTED:
      Serial.println("[ETH] Kabl iskljucen");
      eth_connected = false;
      break;
    case ARDUINO_EVENT_ETH_STOP:
      Serial.println("[ETH] Stop");
      eth_connected = false;
      break;
    default:
      break;
  }
}

//  WiFi AP — as fallback
void startWiFiAP() {
  Serial.println("[WiFi] Pokretanje Access Point-a...");
  WiFi.mode(WIFI_AP);
  WiFi.softAP(WIFI_AP_SSID, WIFI_AP_PASSWORD);
  delay(500);
  IPAddress apIP = WiFi.softAPIP();
  Serial.print("[WiFi] AP aktivan. SSID: ");
  Serial.println(WIFI_AP_SSID);
  Serial.print("[WiFi] Lozinka: ");
  Serial.println(WIFI_AP_PASSWORD);
  Serial.print("[WiFi] IP adresa: ");
  Serial.println(apIP);
  wifi_ap_active = true;
  ip_address = apIP.toString();
  active_network = "WiFi AP";
}

//  I²S init— TX channel (for DAC, master mode)
void setupI2S_TX() {
  Serial.println("[I2S] Inicijalizacija TX (DAC) - master mod...");

  i2s_config_t tx_config = {
    .mode = (i2s_mode_t)(I2S_MODE_MASTER | I2S_MODE_TX),
    .sample_rate = SAMPLE_RATE,
    .bits_per_sample = (i2s_bits_per_sample_t)BITS_PER_SAMPLE,
    .channel_format = I2S_CHANNEL_FMT_RIGHT_LEFT,
    .communication_format = I2S_COMM_FORMAT_STAND_I2S,
    .intr_alloc_flags = ESP_INTR_FLAG_LEVEL1,
    .dma_buf_count = DMA_BUF_COUNT,
    .dma_buf_len = DMA_BUF_LEN,
    .use_apll = true,           // Audio PLL for excact sample rate
    .tx_desc_auto_clear = true,
    .fixed_mclk = 0
  };

  i2s_pin_config_t tx_pins = {
    .mck_io_num = I2S_PIN_NO_CHANGE,
    .bck_io_num = I2S_TX_BCLK_PIN,
    .ws_io_num  = I2S_TX_LRCK_PIN,
    .data_out_num = I2S_TX_DOUT_PIN,
    .data_in_num  = I2S_PIN_NO_CHANGE
  };

  esp_err_t err = i2s_driver_install(I2S_TX_PORT, &tx_config, 0, NULL);
  if (err != ESP_OK) {
    Serial.printf("[I2S TX] Greska install: %d\n", err);
    return;
  }
  err = i2s_set_pin(I2S_TX_PORT, &tx_pins);
  if (err != ESP_OK) {
    Serial.printf("[I2S TX] Greska set_pin: %d\n", err);
    return;
  }
  i2s_zero_dma_buffer(I2S_TX_PORT);
  Serial.println("[I2S TX] OK");
}

//  I²S init — RX channel (from ADC-a, slave mode)
//  ADC master, ESP32  slave <-   recieving BCK/LRCK from ADC
void setupI2S_RX() {
  Serial.println("[I2S] Inicijalizacija RX (ADC) - slave mod...");

  i2s_config_t rx_config = {
    .mode = (i2s_mode_t)(I2S_MODE_SLAVE | I2S_MODE_RX),
    .sample_rate = SAMPLE_RATE,
    .bits_per_sample = (i2s_bits_per_sample_t)BITS_PER_SAMPLE,
    .channel_format = I2S_CHANNEL_FMT_RIGHT_LEFT,
    .communication_format = I2S_COMM_FORMAT_STAND_I2S,
    .intr_alloc_flags = ESP_INTR_FLAG_LEVEL1,
    .dma_buf_count = DMA_BUF_COUNT,
    .dma_buf_len = DMA_BUF_LEN,
    .use_apll = false,          // slave modue = clk from ADC
    .tx_desc_auto_clear = false,
    .fixed_mclk = 0
  };

  i2s_pin_config_t rx_pins = {
    .mck_io_num = I2S_PIN_NO_CHANGE,
    .bck_io_num = I2S_RX_BCLK_PIN,
    .ws_io_num  = I2S_RX_LRCK_PIN,
    .data_out_num = I2S_PIN_NO_CHANGE,
    .data_in_num  = I2S_RX_DIN_PIN
  };

  esp_err_t err = i2s_driver_install(I2S_RX_PORT, &rx_config, 0, NULL);
  if (err != ESP_OK) {
    Serial.printf("[I2S RX] Greska install: %d\n", err);
    return;
  }
  err = i2s_set_pin(I2S_RX_PORT, &rx_pins);
  if (err != ESP_OK) {
    Serial.printf("[I2S RX] Greska set_pin: %d\n", err);
    return;
  }
  Serial.println("[I2S RX] OK");
}

//  generating single data (sample) — returns 16-bit signed int
inline int16_t generateSample(WaveformType wave, double &phase,
                              float freq, float amp, bool muted) {
  if (muted) return 0;

  // Inkrement phase — phase in rad [0, 2π)
  double phase_inc = (2.0 * M_PI * freq) / (double)SAMPLE_RATE;
  phase += phase_inc;
  if (phase >= 2.0 * M_PI) phase -= 2.0 * M_PI;

  double normalized = phase / (2.0 * M_PI);  // [0, 1)
  double value = 0.0;  // [-1, 1]

  switch (wave) {
    case WAVEFORM_SINE:
      value = sin(phase);
      break;
    case WAVEFORM_SQUARE:
      value = (normalized < 0.5) ? 1.0 : -1.0;
      break;
    case WAVEFORM_TRIANGLE:
      if (normalized < 0.5) {
        value = -1.0 + 4.0 * normalized;       //  -1 -->   1
      } else {
        value = 3.0 - 4.0 * normalized;        //  1  -->  -1
      }
      break;
  }

  // Skale with amplitude and convert in 16-bit signed
  //  0.9 max  (clipping DAC)
  double scaled = value * amp * 0.9 * 32767.0;
  if (scaled >  32767.0) scaled =  32767.0;
  if (scaled < -32768.0) scaled = -32768.0;
  return (int16_t)scaled;
}

//  analyze recieved signal — freq (zero-crossing) i RMS amplitude
void analyzeSignal(int16_t *samples, int count, int channel,
                   float &out_freq, float &out_rms) {
  // RMS = sqrt(mean(samples^2))
  double sum_sq = 0.0;
  for (int i = 0; i < count; i++) {
    double v = (double)samples[i];
    sum_sq += v * v;
  }
  out_rms = sqrt(sum_sq / (double)count);

  // Frekvencija pomoću zero-crossing detekcije
  // Brojimo koliko puta signal prelazi kroz nulu (sa - na +)
  int crossings = 0;
  for (int i = 1; i < count; i++) {
    if (samples[i-1] < 0 && samples[i] >= 0) {
      crossings++;
    }
  }
  // Vreme trajanja bafera (u sekundama)
  double duration = (double)count / (double)SAMPLE_RATE;
  if (duration > 0.0) {
    out_freq = (float)((double)crossings / duration);
  } else {
    out_freq = 0.0;
  }
}

// ============================================================================
//  POPUNJAVANJE TX bafera sa novim uzorcima
// ============================================================================
void fillTxBuffer() {
  for (int i = 0; i < BUFFER_SAMPLES; i++) {
    int16_t sL = generateSample(wave_left,  phase_left,  freq_left,  amp_left,  mute_left);
    int16_t sR = generateSample(wave_right, phase_right, freq_right, amp_right, mute_right);
    // Interleaved format: L, R, L, R, ...
    tx_buffer[i*2 + 0] = sL;
    tx_buffer[i*2 + 1] = sR;
  }
}

// ============================================================================
//  WEB SERVER handlers
// ============================================================================
void handleRoot() {
  // Serviraj glavnu HTML stranicu iz webpage.h
  http_server.send_P(200, "text/html", WEBPAGE_HTML);
}

void handleStatus() {
  // Vrati JSON sa trenutnim stanjem
  String json = "{";
  json += "\"network\":\""  + active_network + "\",";
  json += "\"ip\":\""        + ip_address    + "\",";
  json += "\"freq_left\":"   + String(freq_left, 1) + ",";
  json += "\"freq_right\":"  + String(freq_right, 1) + ",";
  json += "\"amp_left\":"    + String(amp_left, 2) + ",";
  json += "\"amp_right\":"   + String(amp_right, 2) + ",";
  json += "\"wave_left\":"   + String((int)wave_left) + ",";
  json += "\"wave_right\":"  + String((int)wave_right) + ",";
  json += "\"mute_left\":"   + String(mute_left  ? "true" : "false") + ",";
  json += "\"mute_right\":"  + String(mute_right ? "true" : "false") + ",";
  json += "\"sample_rate\":" + String(SAMPLE_RATE);
  json += "}";
  http_server.send(200, "application/json", json);
}

void handleNotFound() {
  http_server.send(404, "text/plain", "Not Found");
}

// ============================================================================
//  WebSocket handler — prima komande sa web stranice, šalje rezultate analize
// ============================================================================
void onWebSocketEvent(uint8_t client_num, WStype_t type,
                     uint8_t *payload, size_t length) {
  switch (type) {
    case WStype_CONNECTED:
      Serial.printf("[WS] Klijent %u povezan\n", client_num);
      break;
    case WStype_DISCONNECTED:
      Serial.printf("[WS] Klijent %u iskljucen\n", client_num);
      break;
    case WStype_TEXT: {
      // Format komande: "KEY=VALUE"
      String msg = String((char*)payload).substring(0, length);
      int eq = msg.indexOf('=');
      if (eq < 0) break;
      String key = msg.substring(0, eq);
      String val = msg.substring(eq + 1);

      if      (key == "wave_left")   wave_left   = (WaveformType)val.toInt();
      else if (key == "wave_right")  wave_right  = (WaveformType)val.toInt();
      else if (key == "freq_left")   freq_left   = val.toFloat();
      else if (key == "freq_right")  freq_right  = val.toFloat();
      else if (key == "amp_left")    amp_left    = val.toFloat();
      else if (key == "amp_right")   amp_right   = val.toFloat();
      else if (key == "mute_left")   mute_left   = (val == "1" || val == "true");
      else if (key == "mute_right")  mute_right  = (val == "1" || val == "true");

      Serial.printf("[WS] %s = %s\n", key.c_str(), val.c_str());
      break;
    }
    default:
      break;
  }
}

// ============================================================================
//  Slanje podataka analize i grafika preko WebSocket-a
// ============================================================================
void sendDataToClients() {
  // Formatiraj JSON sa svim podacima
  String json = "{\"type\":\"data\",";
  json += "\"network\":\"" + active_network + "\",";
  json += "\"detected_freq_left\":"  + String(detected_freq_left, 1) + ",";
  json += "\"detected_freq_right\":" + String(detected_freq_right, 1) + ",";
  json += "\"rms_left\":"  + String(rms_left, 1) + ",";
  json += "\"rms_right\":" + String(rms_right, 1) + ",";

  // Niz uzoraka za grafik (downsample-ovan)
  json += "\"graph_left\":[";
  for (int i = 0; i < GRAPH_SAMPLES; i++) {
    json += String(graph_buffer_left[i]);
    if (i < GRAPH_SAMPLES - 1) json += ",";
  }
  json += "],\"graph_right\":[";
  for (int i = 0; i < GRAPH_SAMPLES; i++) {
    json += String(graph_buffer_right[i]);
    if (i < GRAPH_SAMPLES - 1) json += ",";
  }
  json += "]}";

  ws_server.broadcastTXT(json);
}

// ============================================================================
//  SETUP
// ============================================================================
void setup() {
  Serial.begin(115200);
  delay(500);
  Serial.println();
  Serial.println("================================================");
  Serial.println("  PROJEKAT F - Signal Generator + Monitor");
  Serial.println("  ESP32-ETH01 + WM8782S ADC + PCM5102A DAC");
  Serial.println("================================================");

  // ----- 1. Pokušaj Ethernet konekcije -----
  Serial.println("\n[INIT] Pokusavam Ethernet...");
  WiFi.onEvent(onEthEvent);
  ETH.begin();

  unsigned long start = millis();
  while (!eth_connected && (millis() - start < ETH_TIMEOUT_MS)) {
    delay(100);
  }

  // ----- 2. Ako Ethernet nije uspeo, pokreni WiFi AP -----
  if (!eth_connected) {
    Serial.println("[INIT] Ethernet nije aktivan posle 3s -> startujem WiFi AP");
    startWiFiAP();
  } else {
    Serial.println("[INIT] Ethernet aktivan");
  }

  // ----- 3. Inicijalizuj I²S kanale -----
  setupI2S_TX();
  setupI2S_RX();

  // ----- 4. Inicijalizuj HTTP server -----
  http_server.on("/", handleRoot);
  http_server.on("/status", handleStatus);
  http_server.onNotFound(handleNotFound);
  http_server.begin();
  Serial.printf("[HTTP] Server pokrenut na portu %d\n", HTTP_PORT);

  // ----- 5. Inicijalizuj WebSocket server -----
  ws_server.begin();
  ws_server.onEvent(onWebSocketEvent);
  Serial.printf("[WS] Server pokrenut na portu %d\n", WEBSOCKET_PORT);

  Serial.println("\n================================================");
  Serial.print("  Otvori u pretrazivacu: http://");
  Serial.println(ip_address);
  Serial.println("================================================\n");
}

// ============================================================================
//  LOOP — glavna petlja
// ============================================================================
void loop() {
  // ----- 1. Obradi HTTP i WebSocket -----
  http_server.handleClient();
  ws_server.loop();

  // ----- 2. Generiši i pošalji nove TX uzorke ka DAC-u -----
  fillTxBuffer();
  size_t bytes_written = 0;
  i2s_write(I2S_TX_PORT, tx_buffer, sizeof(tx_buffer), &bytes_written,
            10 / portTICK_PERIOD_MS);

  // ----- 3. Primi nove RX uzorke od ADC-a -----
  size_t bytes_read = 0;
  i2s_read(I2S_RX_PORT, rx_buffer, sizeof(rx_buffer), &bytes_read,
           10 / portTICK_PERIOD_MS);

  // ----- 4. Razdvoj L/R kanale za analizu -----
  int16_t samples_left[BUFFER_SAMPLES];
  int16_t samples_right[BUFFER_SAMPLES];
  for (int i = 0; i < BUFFER_SAMPLES; i++) {
    samples_left[i]  = rx_buffer[i*2 + 0];
    samples_right[i] = rx_buffer[i*2 + 1];
  }

  // ----- 5. Analiziraj signale -----
  float f_l, f_r, rms_l, rms_r;
  analyzeSignal(samples_left,  BUFFER_SAMPLES, 0, f_l, rms_l);
  analyzeSignal(samples_right, BUFFER_SAMPLES, 1, f_r, rms_r);
  detected_freq_left  = f_l;
  detected_freq_right = f_r;
  rms_left  = rms_l;
  rms_right = rms_r;

  // ----- 6. Pripremi grafik buffer (downsample) -----
  int step = BUFFER_SAMPLES / GRAPH_SAMPLES;
  if (step < 1) step = 1;
  for (int i = 0; i < GRAPH_SAMPLES; i++) {
    int src = i * step;
    if (src >= BUFFER_SAMPLES) src = BUFFER_SAMPLES - 1;
    graph_buffer_left[i]  = samples_left[src];
    graph_buffer_right[i] = samples_right[src];
  }

  // ----- 7. Pošalji podatke na web stranicu (10×/sekund) -----
  unsigned long now = millis();
  if (now - last_websocket_send >= WEBSOCKET_INTERVAL_MS) {
    last_websocket_send = now;
    sendDataToClients();
  }
}

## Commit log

2026-06-09 KiCad Schematic v1.0
    [ESP32_Eth_ADC_DAC.kicad_pcb, ESP32_Eth_ADC_DAC.kicad_sch]
2026-06-26 Git fixed
    [ESP32_Eth_ADC_DAC.kicad_pcb, ESP32_Eth_ADC_DAC.kicad_sch]
2026-06-26 Version 3.2
    [ESP32_Eth_ADC_DAC.kicad_pcb]
